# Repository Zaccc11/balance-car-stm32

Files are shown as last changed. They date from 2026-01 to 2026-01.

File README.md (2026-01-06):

# balance-car-stm32

Self-balancing robot built on **STM32F103 (Blue Pill)** with **MPU6050 IMU** and real-time control.  
This repository includes firmware (`src/`) and custom control PCB design assets (`pcb/`).

---

## What I Built
- **Real-time control firmware** on STM32 (interrupt/timer driven)
- **Nested PID control** for balancing (and optional velocity loop / remote control input)
- **IMU interface** (MPU6050 over I²C) for tilt estimation
- **Peripheral interfaces** for OLED display, Bluetooth module (JDY-31), and ultrasonic sensor
- **Custom control PCB** integrating MCU, power regulation, and connectors
## showcase

---

DEMO

-  [`images/`](images) / [`pcb/`](pcb) 

---

## Hardware Overview
Typical setup for this project:
- MCU: **STM32F103C8T6**
- IMU: **MPU6050**
- TB6612FNG Motor driver module + two MG513P30 hall encoder dc motor
- 0.96-inch OLED display, JDY-31 Bluetooth module, HC-SR04 ultrasonic sensor
- Power input: **12 V** (regulated on-board via DC-DC)

---

## PCB
The PCB integrates power input, DC-DC regulation, STM32 header footprint, and connectors for sensors and peripherals.

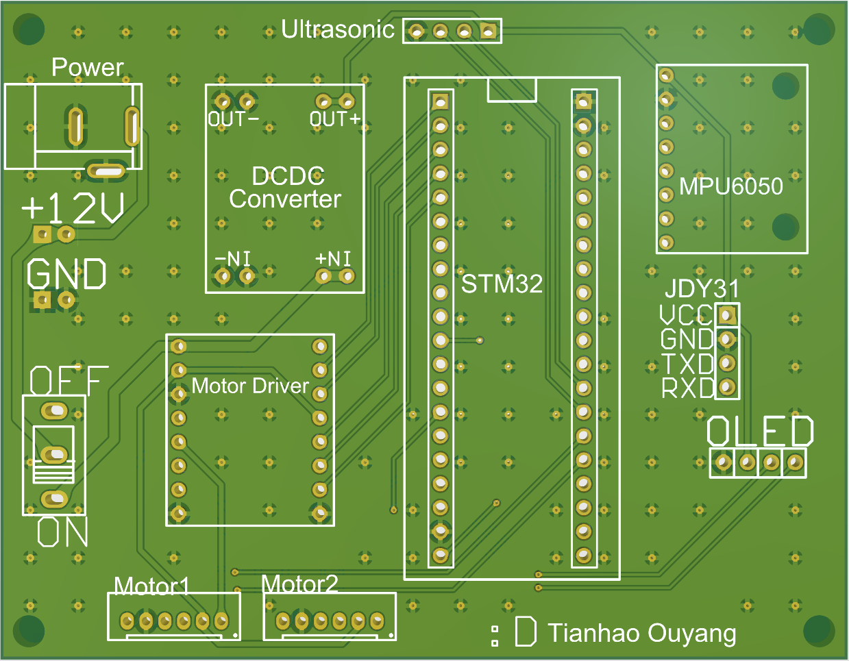
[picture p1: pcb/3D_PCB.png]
PCB Layout


If you want the PCB-specific README, see: [`pcb/`](pcb)

---

## Repository Structure
```text
balance-car-stm32/
├─ src/                Firmware source code
├─ pcb/                PCB design notes/assets (screenshots, PDFs, etc.)
├─ images/             Images used by README (PCB/layout/photos)
├─ Balanced Car.uvprojx  Keil uVision project file
├─ .gitignore
└─ .clang-format

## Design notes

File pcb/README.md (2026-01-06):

# Self-Balancing Car Control PCB
## Overview
This PCB serves as the central control board for a self-balancing car system. It integrates the microcontroller, motor driver interface, power supply, and peripheral connectors into a single compact board.

Main functions:
- STM32-based real-time control
- Dual motor control interface
- IMU sensing for balance estimation
- Wireless communication and display support
- On-board DC-DC power regulation

## Key Components & Interfaces

### Microcontroller
- stmf103c8t6

### Power System
- 12 V lithium ion battery input

### Motor Control
- 2x PH2.0-6Pin

### Sensors & Peripherals
- MPU6050 IMU
- HC-SR04 Ultrasonic sensor
- 0.96inch OLED display
- JDY-31 Bluetooth module
- TB6612FNG Motor driver
- MP1584EN 12V-5V DCDC converter

## Tools
- PCB Design: Altium Designer  
- Board Type: 2-layer PCB

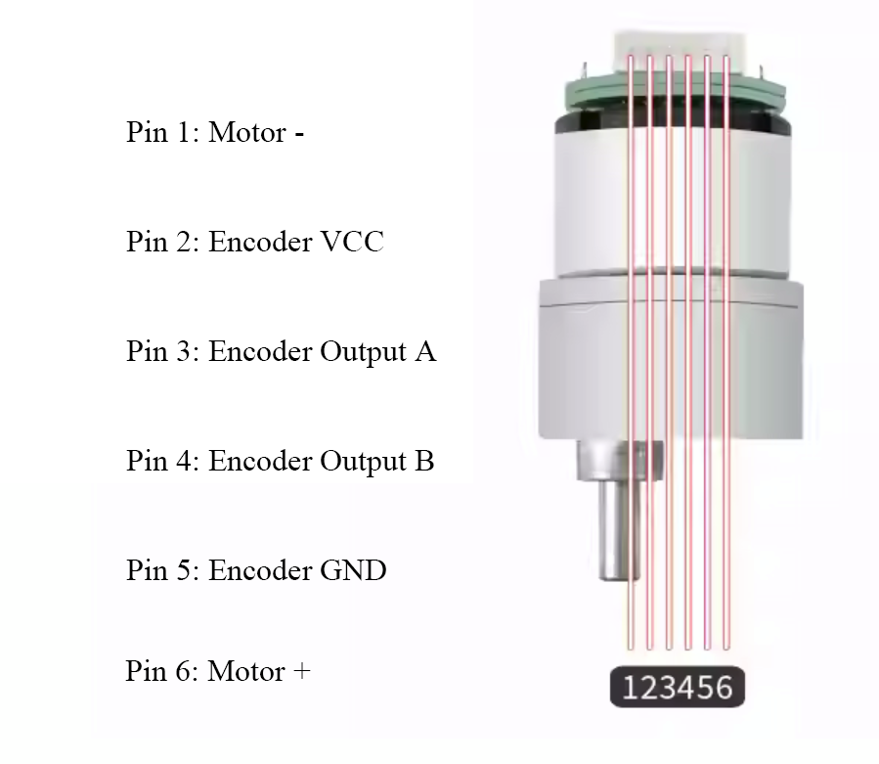
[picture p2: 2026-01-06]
images/MG513 Hall Encoder Motor Pinout.png

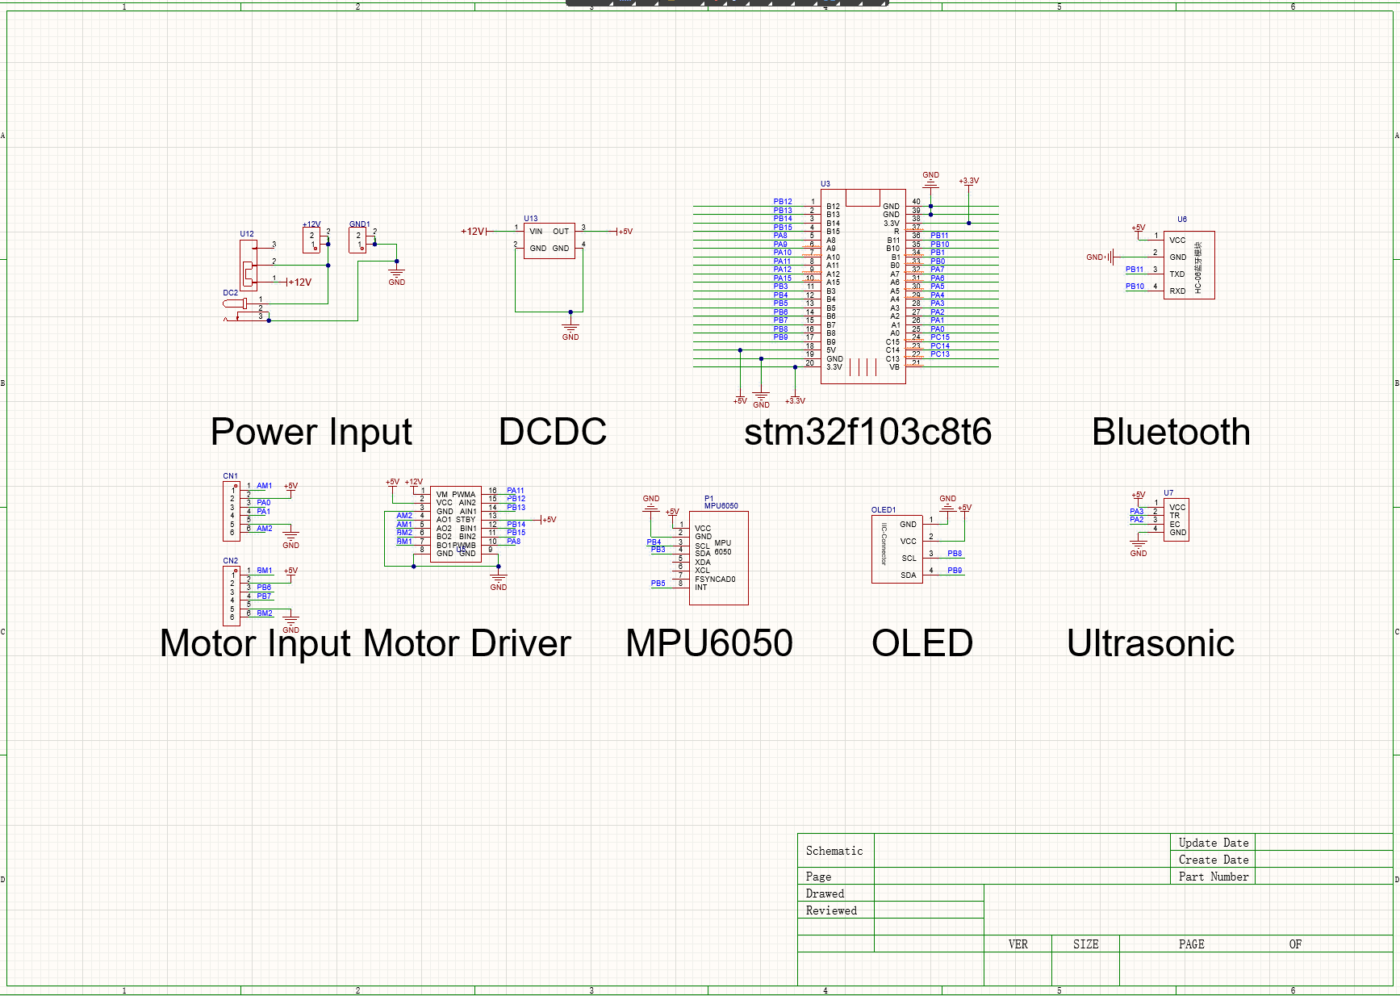
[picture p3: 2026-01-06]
pcb/PCB Schematic.png

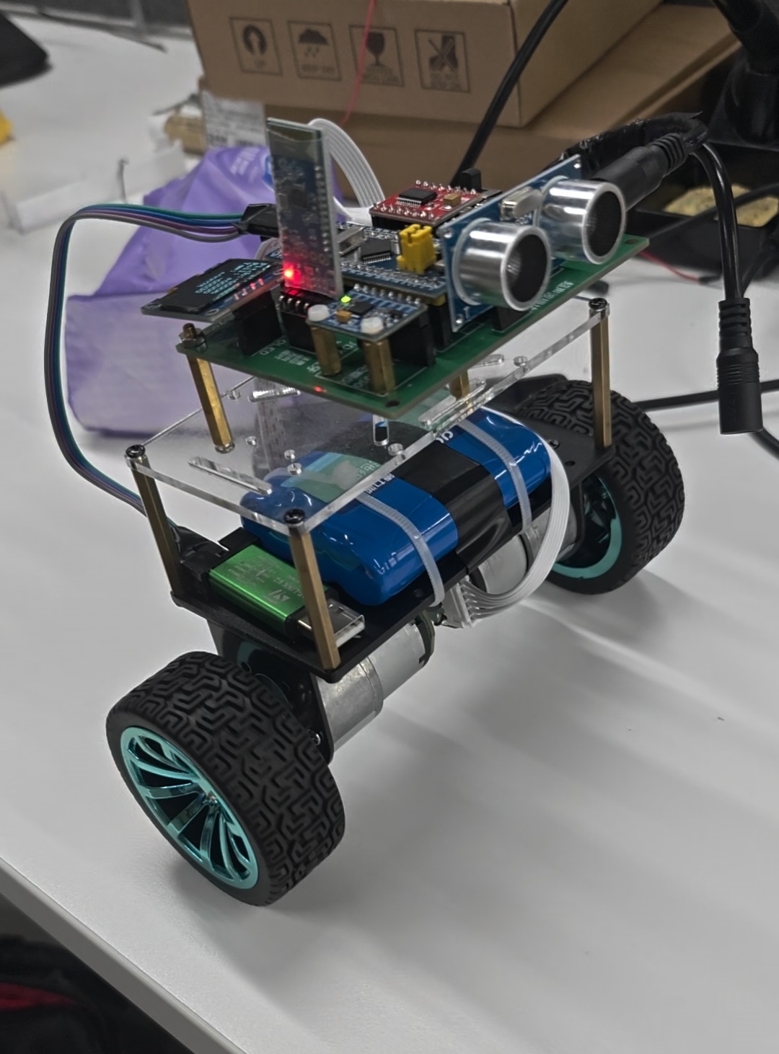
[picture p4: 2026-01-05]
images/Balance_Car.jpg

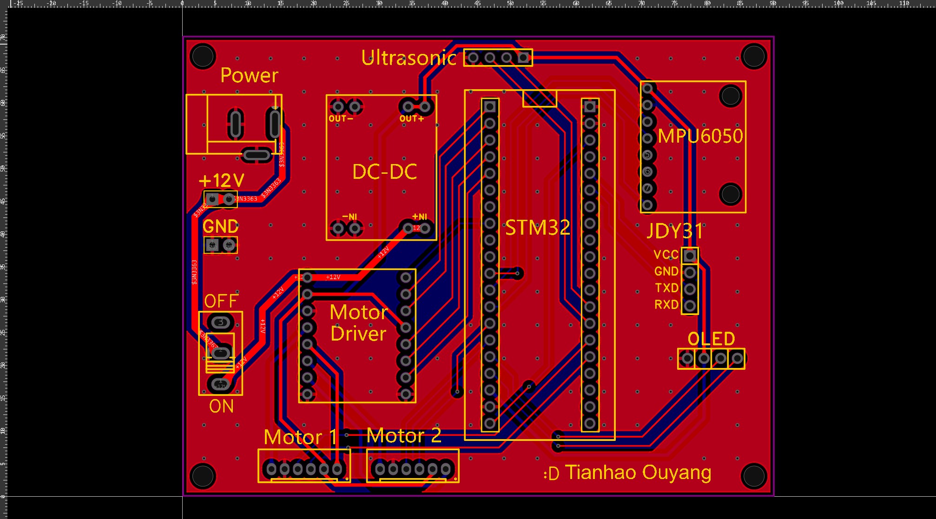
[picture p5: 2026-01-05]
pcb/PCB Board.jpg

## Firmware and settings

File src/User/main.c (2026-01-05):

#include "stm32f10x.h"                  // Device header
#include "sys.h"

/*2025/6/30: Tested Motor 2 to ensure its avaibility, should test out Motor 1 the same, then goes for PID control.
  
	Two Motor, Motor 1 and 2
	To control Motor 1, Configure PB12 and PB13
	To control Motor 2, Configure PB14 and PB15
	Use Motor_PWN_Init(arr,psc) to set arr and psc
	Use Motor_SetSpeed(arr) to set the frequency of the motor
*/

// 全局变量定义区
float Pitch, Roll, Yaw; // 角度
int16_t gyrox, gyroy, gyroz; // 陀螺仪--角速度
int16_t aacx, aacy, aacz; // 加速度
int Encoder_Left, Encoder_Right; // 编码器数据（速度）
int MOTO1, MOTO2;
int PWM_MAX = 7200, PWM_MIN = -7200;

char stop = 0;
u8 Fore = 0, Back = 0, Left = 0, Right = 0;

//PID.c variable
float Med_Angle=-3;		//机械中值。---在这里修改你的机械中值即可。
float Target_Speed=0;	//期望速度（俯仰）。---二次开发接口，用于控制小车前进后退及其速度。
float Turn_Speed=0;		//期望速度（偏航）

float 
		Balance_Kp=220,
		Balance_Kd=0.7;
		
float
		Velocity_Kp=0.3,
		Velocity_Ki=0.0015;
float
		Turn_Kp=-0.6,
		Turn_Kd=0;

int Vertical_out,Velocity_out,Turn_out;//直立环&速度环&转向环 的输出变量
uint8_t ID;								//定义用于存放ID号的变量




int main(void)
{
	NVIC_Config();
	//uart1_init(115200);	

	//uart3_init(9600);//先9600  
	OLED_Init();
  MPU6050_Init();
	mpu_dmp_init();
	MPU6050_EXTI_Init();
	Encoder_Init_TIM2();
	Encoder_Init_TIM4();
	Motor_PWN_Init(7199,0);
	TIM3_Int_Init();
OLED_ShowString(1, 1, "Pitch:");
			OLED_ShowString(2, 1, "Roll:");
	OLED_ShowString(3, 1, "Yaw:");
	
	while (1){

		OLED_ShowSignedNum(1, 7, (int)Pitch,  5);

    OLED_ShowSignedNum(2, 7, (int)Roll,   5);
    
		OLED_ShowSignedNum( 3, 7, (int)Yaw,    5);
		OLED_ShowSignedNum(4,5,(int)((Encoder_Left+Encoder_Right)*2.38),5);	
                
	}
	

                



}

void TIM3_Int_Init(void)
{
		GPIO_InitTypeDef GPIO_InitStruct;
		TIM_TimeBaseInitTypeDef TIM_TimeBaseStructure;
//		NVIC_InitTypeDef NVIC_InitStructure;

		RCC_APB1PeriphClockCmd(RCC_APB1Periph_TIM3, ENABLE); //时钟使能
		RCC_APB2PeriphClockCmd(RCC_APB2Periph_GPIOA, ENABLE);
			
		
		GPIO_InitStruct.GPIO_Mode=GPIO_Mode_Out_PP;//设置为推挽输出
		GPIO_InitStruct.GPIO_Pin=GPIO_Pin_3;
		GPIO_InitStruct.GPIO_Speed=GPIO_Speed_50MHz;
		GPIO_Init(GPIOA,&GPIO_InitStruct);

		GPIO_InitStruct.GPIO_Mode=GPIO_Mode_IN_FLOATING;
		GPIO_InitStruct.GPIO_Pin=GPIO_Pin_2;
		GPIO_Init(GPIOA,&GPIO_InitStruct);
	
		//定时器3初始化
		TIM_TimeBaseStructure.TIM_Period = 999; //ARR
		TIM_TimeBaseStructure.TIM_Prescaler =7199; //PSC
		TIM_TimeBaseStructure.TIM_ClockDivision = TIM_CKD_DIV1;
		TIM_TimeBaseStructure.TIM_CounterMode = TIM_CounterMode_Up; //向上计数模式
		TIM_TimeBaseInit(TIM3, &TIM_TimeBaseStructure);
		
//		TIM_ITConfig(TIM3,TIM_IT_Update,ENABLE );//使能制定TIM3中断，允许更新中断
//		//中断设置
//		NVIC_PriorityGroupConfig(NVIC_PriorityGroup_2);
//		NVIC_InitStructure.NVIC_IRQChannel = TIM3_IRQn;
//		NVIC_InitStructure.NVIC_IRQChannelPreemptionPriority = 0;
//		NVIC_InitStructure.NVIC_IRQChannelSubPriority = 3;
//		NVIC_InitStructure.NVIC_IRQChannelCmd = ENABLE;
//		NVIC_Init(&NVIC_InitStructure);

		TIM_Cmd(TIM3, DISABLE);

/*void TIM3_IRQHandler(void)
{
    if (TIM_GetITStatus(TIM3, TIM_IT_Update) != RESET)
    {
        dmp_data_ready = 1;

        TIM_ClearITPendingBit(TIM3, TIM_IT_Update);
    }
}
*/
}

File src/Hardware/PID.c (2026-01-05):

#include "stm32f10x.h"
#include "sys.h"


extern int length;

#define SPEED_Y 10   //俯仰(前后)最大设定速度
#define SPEED_Z 100//偏航(左右)最大设定速度 


int Upstanding(float Med, float Angle, float Gyro_X) {
		int PWM_Out;
		PWM_Out = Balance_Kp*(Angle-Med)+Balance_Kd*(Gyro_X-0);
		return PWM_Out;
}
u8 mpu6050_data_ready;

int Velocity(int Target, int Encoder_Left, int Encoder_Right){
	static int Encoder_S, EnC_Err_Lowout_Buffer, EnC_Err_Lowout, Encoder_Err, PWM_out;
	float a = 0.7;
	
	Encoder_Err = Target_Speed-(Encoder_Left+Encoder_Right);
	EnC_Err_Lowout = (1-a)*Encoder_Err+a*EnC_Err_Lowout_Buffer;
	EnC_Err_Lowout_Buffer = EnC_Err_Lowout;
	Encoder_S += EnC_Err_Lowout;
	Encoder_S = Encoder_S>5000?5000:(Encoder_S<(-5000)?(-5000):Encoder_S);
	
	if(stop==1) Encoder_S = 0, stop = 0;
	
	PWM_out = Velocity_Kp*EnC_Err_Lowout+Velocity_Ki*Encoder_S;
	return PWM_out;
	
}

int Turn(int32_t Gyro_Z, int32_t RC) {
    int PWM_Out;
		PWM_Out = Turn_Kp*Gyro_Z + Turn_Kd*RC;
		return PWM_Out;
    
}

u8 turn_off(float angle) {
	u8 temp;
	if (angle<-40||angle>40) {
		temp = 1;
		AIN1=0;                                            
		AIN2=0;
		BIN1=0;
		BIN2=0;
	}
	else {
		temp = 0;
	}
	return temp;
}
		

void EXTI9_5_IRQHandler(void)
{
		int PWM_out;
    if (EXTI_GetITStatus(EXTI_Line5)!=0)
    {
			if(PBin(5) == 0){
        EXTI_ClearITPendingBit(EXTI_Line5);
            // 读取编码器、传感器、计算 PID
				Encoder_Left=-Read_Speed(2);//电机是相对安装，刚好相差180度，为了编码器输出极性一致，就需要对其中一个取反。
				Encoder_Right=Read_Speed(4);

            // 只用上一帧的 Pitch、gyro、accel 来做 PID
						mpu_dmp_get_data(&Roll,&Pitch,&Yaw);	
						MPU_Get_Gyroscope(&gyroy,&gyrox,&gyroz);	//陀螺仪
						MPU_Get_Accelerometer(&aacx,&aacy,&aacz);
						
						
						if((Left==0)&&(Right==0))Turn_Kd=-0.7;//若无左右转向指令，则开启转向约束
				
				
						Target_Speed=Target_Speed>SPEED_Y?SPEED_Y:(Target_Speed<-SPEED_Y?(-SPEED_Y):Target_Speed);
						Turn_Speed=Turn_Speed>SPEED_Z?SPEED_Z:(Turn_Speed<-SPEED_Z?(-SPEED_Z):Turn_Speed);
            Velocity_out = Velocity(Target_Speed, Encoder_Left,Encoder_Right);
            Vertical_out = Upstanding(Velocity_out+Med_Angle, Pitch, gyroy);
            Turn_out = Turn(gyroz, Turn_Speed);
						
						PWM_out=Vertical_out;
						MOTO1=PWM_out-Turn_out;//左电机
						MOTO2=PWM_out+Turn_out;//右电机
						Limit(&MOTO1,&MOTO2);	 //PWM限幅			
					
						Load(MOTO1,MOTO2);		 //加载到电机上。
						
			
						Stop(&Med_Angle,&Pitch);//安全检测
			}
			
    }
}

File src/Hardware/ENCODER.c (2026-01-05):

#include "stm32f10x.h"


void Encoder_Init_TIM2(void){
    GPIO_InitTypeDef GPIO_InitStructure;
    TIM_TimeBaseInitTypeDef TIM_TimeBaseStructure;
    TIM_ICInitTypeDef TIM_ICInitStructure;
    RCC_APB2PeriphClockCmd(RCC_APB2Periph_GPIOA, ENABLE);
    RCC_APB1PeriphClockCmd(RCC_APB1Periph_TIM2, ENABLE);

    GPIO_InitStructure.GPIO_Pin = GPIO_Pin_0 | GPIO_Pin_1; // PA0 and PA1 for TIM2 CH1 and CH2
    GPIO_InitStructure.GPIO_Mode = GPIO_Mode_IN_FLOATING;
    GPIO_Init(GPIOA, &GPIO_InitStructure);

    TIM_TimeBaseStructure.TIM_Prescaler = 0x0; // No prescaler
    TIM_TimeBaseStructure.TIM_CounterMode = TIM_CounterMode_Up; // Count up
    TIM_TimeBaseStructure.TIM_Period = 0xFFFF; // Max period
    TIM_TimeBaseStructure.TIM_ClockDivision = TIM_CKD_DIV1; // No clock division
    TIM_TimeBaseInit(TIM2, &TIM_TimeBaseStructure);

    TIM_EncoderInterfaceConfig(TIM2, TIM_EncoderMode_TI12, TIM_ICPolarity_Rising, TIM_ICPolarity_Rising);
    TIM_ICStructInit(&TIM_ICInitStructure);
    TIM_ICInitStructure.TIM_ICFilter = 10;
    TIM_ICInit(TIM2, &TIM_ICInitStructure);
    TIM_ClearFlag(TIM2, TIM_FLAG_Update); // Clear the update flag
    TIM_ITConfig(TIM2, TIM_IT_Update, ENABLE);

    TIM_SetCounter(TIM2, 0);

    TIM_Cmd(TIM2, ENABLE); // Enable TIM2

}

void Encoder_Init_TIM4(void) {
    GPIO_InitTypeDef GPIO_InitStructure;
    TIM_TimeBaseInitTypeDef TIM_TimeBaseStructure;
    TIM_ICInitTypeDef TIM_ICInitStructure;
    RCC_APB2PeriphClockCmd(RCC_APB2Periph_GPIOB, ENABLE);
    RCC_APB1PeriphClockCmd(RCC_APB1Periph_TIM4, ENABLE);

    GPIO_InitStructure.GPIO_Pin = GPIO_Pin_6 | GPIO_Pin_7; // PA0 and PA1 for TIM2 CH1 and CH2
    GPIO_InitStructure.GPIO_Mode = GPIO_Mode_IN_FLOATING;
    GPIO_Init(GPIOB, &GPIO_InitStructure);

    TIM_TimeBaseStructure.TIM_Prescaler = 0; // No prescaler
    TIM_TimeBaseStructure.TIM_CounterMode = TIM_CounterMode_Up; // Count up
    TIM_TimeBaseStructure.TIM_Period = 0xFFFF; // Max period
    TIM_TimeBaseStructure.TIM_ClockDivision = TIM_CKD_DIV1; // No clock division
    TIM_TimeBaseInit(TIM4, &TIM_TimeBaseStructure);

    TIM_EncoderInterfaceConfig(TIM4, TIM_EncoderMode_TI12, TIM_ICPolarity_Rising, TIM_ICPolarity_Rising);
    TIM_ICStructInit(&TIM_ICInitStructure);
    TIM_ICInitStructure.TIM_ICFilter = 10;
    TIM_ICInit(TIM4, &TIM_ICInitStructure);
    TIM_ClearFlag(TIM4, TIM_FLAG_Update); // Clear the update flag
    TIM_ITConfig(TIM4, TIM_IT_Update, ENABLE);

    TIM_SetCounter(TIM4, 0);

    TIM_Cmd(TIM4, ENABLE); // Enable TIM4
}

	int Read_Speed(int TIMx)
{
	int value_1;
	switch(TIMx)
	{
		case 2:value_1=(short)TIM_GetCounter(TIM2);TIM_SetCounter(TIM2,0);break;//IF是定时器2，1.采集编码器的计数值并保存。2.将定时器的计数值清零。
		case 4:value_1=(short)TIM_GetCounter(TIM4);TIM_SetCounter(TIM4,0);break;
		default:value_1=0;
	}
	return value_1;
}

void TIM2_IRQHandler(void)
{
	if(TIM_GetITStatus(TIM2,TIM_IT_Update)!=0)
	{
		TIM_ClearITPendingBit(TIM2,TIM_IT_Update);
	}
}
	
void TIM4_IRQHandler(void)
{
	if(TIM_GetITStatus(TIM4,TIM_IT_Update)!=0)
	{
		TIM_ClearITPendingBit(TIM4,TIM_IT_Update);
	}
}

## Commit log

2026-01-06 Fix formatting of motor driver and DCDC converter
2026-01-06 Rename 'Demo' section to 'showcase' and update links
    Updated the demo section to showcase images and PCB.
2026-01-06 Rename 3D PCB.png to 3D_\PCB.png
2026-01-06 Fix PCB image filename case sensitivity
